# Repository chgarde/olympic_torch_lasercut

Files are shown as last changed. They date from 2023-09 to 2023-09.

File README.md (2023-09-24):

# Torche olympique 2024 à réaliser en découpe laser
# Fête de la science 2023 / Lou Fabiloub

## Introduction
Il s'agit ici de préparer une torche olympique en découpe laser dans laquelle on viendra insérer un montage électronique simulant la flamme.

## Etapes

### Etape 1 : Vectorisation
Récupération de l'image en format jpg.
Détourage via gimp en utilisant le ciseau magique, puis "selection to path" > export path > svg.
reprise sous inkscape pour obtenir torche_contour.dxf
On en profite pour exporter le logo svg en dxf aussi en cochant toutes les options. (ROBO-MASTER, LOWPOLY, Flatten Bez, Base Unit=mm)

### Etape 2 : Dessin en 3D et préparation découpe.
Réalisé sous openscad.
Une partie de la complexité est la prise en compte du kerf (largeur du faisceau laser) qu'il faut parfois retirer, parfois ajouter.
Il est important que l'épaisseur soit paramétrable car on ne la connait en général qu'une fois que l'on a la planche de bois sous la main !

### Etape 3 : Réalisation d'une vidéo
Openscad permet de réaliser une vidéo et d'enregistrer toutes les images de celle-ci.
Il suffit ensuite de les rassembler avec ffmpeg :
pour un mp4 :
```ffmpeg -framerate 30 -pattern_type glob -i '*.png'   -c:v libx264 -pix_fmt yuv420p -vf "pad=ceil(iw/2)*2:ceil(ih/2)*2" out.mp4```

pour un gif
```ffmpeg -pattern_type glob -i '*.png'  -vsync 2 -safe 0 -loop 0 -y out.gif```

### Etape 4 : Projection en 2D et Planification de la découpe
Assemblage des différents éléments dans inkscape pour faire tenir sur des plaques 500x300mm
![alt text](https://github.com/chgarde/olympic_torch_lasercut/blob/main/step3/out/out.gif?raw=true)

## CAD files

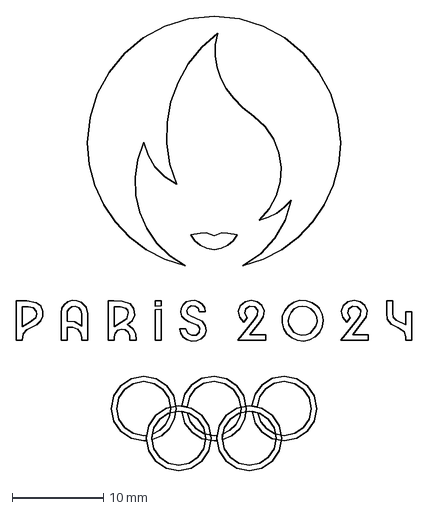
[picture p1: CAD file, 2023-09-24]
step1/out/Logo_JO_d'été_-_Paris_2024.dxf
43.3 x 49.8 mm

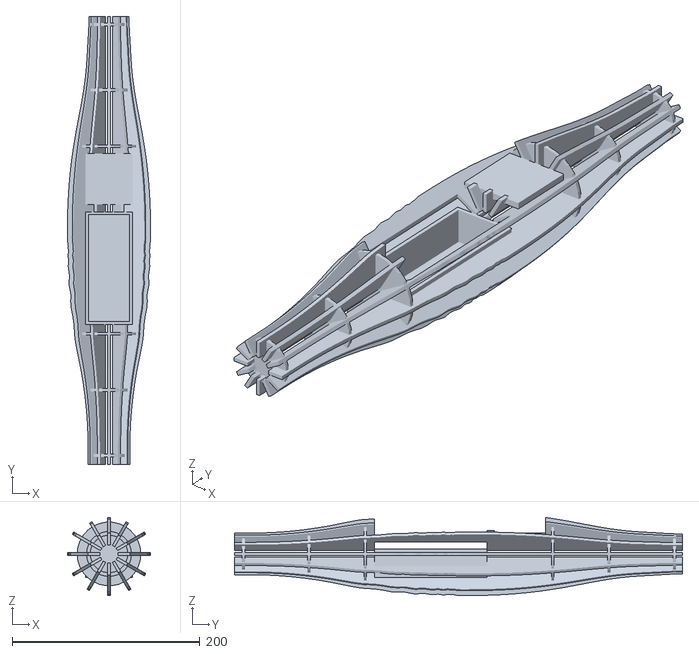
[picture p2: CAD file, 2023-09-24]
step2/torchev2.stl
88.8 x 477.8 x 83.3

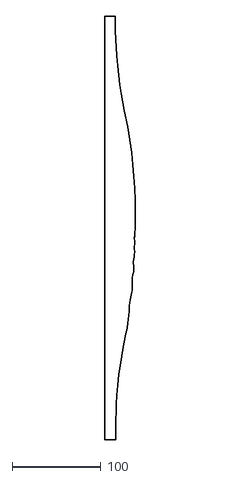
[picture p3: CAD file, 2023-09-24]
step1/out/torche_contour.dxf
34.8 x 477.8

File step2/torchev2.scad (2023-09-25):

a=0; // decalage d'angle.
ep=3.3; // epaisseur du bois
nb=12; // nb de pales
h=480; // hauteur totale
kerf=0.1; // kerf du laser
logo_ep=5; // epaisseur de la plaque logo

profile_file="../step1/out/torche_contour.dxf";
logo_file="../step1/out/Logo_JO_d'été_-_Paris_2024.dxf";

// bagues: [numéro, hauteur, diamètre int, diamètre ext]
bagues_spec=[
    [0,h/2-10,16,20],
    [1,160,16,24],
    [2,100,26,34]
];

module pales(ep){

    translate([0,-h/2,0]){
        for (i=[0:nb]){
            rotate([0,a+i*(360/nb),0]) translate([9,0,0]) linear_extrude(height = ep, center = true) import(file = profile_file);
        }
    }

}

module pales_cutter(ep){
    difference(){
        children();
        pales(ep-kerf);    
    }
}

module bague(r,ep){
    
        rotate([-90,0,0]) difference(){
            cylinder(h=ep,r=r,center=true);
            cylinder(h=ep+4,r=3,center=true);
        }
}

module mirrorer(v){
    children();
    mirror(v) children();
}


module bagues(ep,seulementInterieur){
    mirrorer([0,1,0]){
        for (s=bagues_spec){
            translate([0,s[1],0]) bague(s[2],ep);
        }
    if (seulementInterieur==false){
        for (s=bagues_spec){
            translate([0,s[1],0]) bague(s[3],ep);
        }
        }
    }
}

module bagues_cutter(ep){
    difference(){
        children();
        bagues(ep-kerf,seulementInterieur=true);    
    }
}


module trouBoite(){
    difference(){
        children();
        for (i=[0:4]){
            translate([0,0,i*10]) hull() boite();
        }
    }
}
module trouLogo(){
    difference(){
        children();
        union(){
        for (i=[1:10]){
            translate([0,0,i*(logo_ep-1)]) logo_plaque();
        }
        translate([0,30,50]) rotate([90,0,0]) cube([50,50,20],center=true);
        }
    }
}


module boite(){
    translate([0,-30,-10])
    difference(){
        cube([50,120,30],center=true);    
            translate([0,0,3]) cube([50-6,120-6,30],center=true);    
    }
}

module logo_plaque(){
    translate([0,65,20]) {
        color("white") cube([50,54,logo_ep],center=true);
        color("red") translate([-23,-27,3]) linear_extrude(1) import(logo_file);
    }

}

module logo_plaque2D(){
    square(50,54);
}

module torche(ep){
    bagues_cutter(ep){
        pales(ep);
    }
}

module torche_cutter(ep){
    difference(){
        children();
        bagues_cutter(ep+kerf){ pales(ep-kerf);}
    }
}

module torche2(){
    trouLogo() trouBoite() torche(ep);
}

// ce module permet d'applatir les coupes en angle afin de récupérer uniquement la plus petite dimension.
module flatteninter(){
    children();
//    intersection(){
//        translate([0,0,ep/2-0.2]) children();
//        translate([0,0,-ep/2+0.2]) children();
//    }
}

module torche2D(){     
    for (i=[0:nb/2-1]){
        //for (i=[0:1]){
         projection(true) translate([(i+1)*100,0,0]) flatteninter() rotate([0,i*(360/nb)-a,0]) torche2();
        }
}


module bagues2D(){
    mirror([1,0,0]){
    for (s=bagues_spec){
        translate([s[0]*70,0,0]){
         projection(true) color("green") rotate([90,0,0]) translate([0,-s[1],0]) torche_cutter(ep) bagues(ep,seulementInterieur=false);
        }
    }
}
}

module plan2D(){
    torche2D();       
    bagues2D();
    translate([-100,-100,0])logo_plaque2D();
}

module plan3D(){
    torche2();
    color("green") bagues(ep,seulementInterieur=false);
    color("blue") boite();
    logo_plaque();
}


// vue 3D
//difference(){
//plan3D();

// vue 2D bagues + pales
plan2D();

// video
//rotate([0,$t*360,0]) plan3D();
//translate([0,200,0]) cube([100,400,100],center=true);
//}

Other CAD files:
archives/torche.scad

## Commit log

2023-09-24 initial revision
    [Logo_JO_d'été_-_Paris_2024.dxf, torche.scad, torche_contour.dxf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]
2023-09-25 added holes + changed ep
    [torchev2.scad]
2023-09-25 added plaque
    [torchev2.scad]
